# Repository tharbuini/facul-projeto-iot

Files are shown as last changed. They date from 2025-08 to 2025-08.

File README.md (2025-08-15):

# facul-projeto-iot

Desenvolvimento de Hardware para IoT.

```mermaid
graph TD
    A["Alimentação 5V / USB-C"] --> B{"Módulo Regulador 3.3V"}
    B --> C["ESP32-C3 Microcontrolador"]

    C -- I2C --> D["Sensor BME280 (Temp, Umid, Pressão)"]
    C -- GPIO (ADC) --> E["Sensor MQ-135 (Gases Poluentes)"]
    C -- Serial (UART) --> F["Sensor PMS5003 (Material Particulado)"]
    C -- I2C --> G["Display OLED 0.96"]
    C -- GPIO --> H["Botão de Ação"]

    C -- Wi-Fi --> I["Internet"]
    I -- MQTT/HTTPS --> J["Plataforma IoT (AWS IoT Core, Google Cloud IoT Core)"]
    J -- Armazenamento/Análise --> K["Banco de Dados / Serviço de Análise"]
    K -- Visualização/Alertas --> L["Dashboard Web / Aplicativo Móvel"]

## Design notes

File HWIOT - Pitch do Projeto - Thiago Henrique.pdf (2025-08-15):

# Projeto AtmoSense

# Thiago Henrique

# Problema e a Solução

### - Problema: qualidade do ar interno pode ser pior que a externa, afetando saúde (alergias, problemas respiratórios) e bem-estar. Não há

monitoramento fácil ou acessível.

### - Solução: dispositivo IoT compacto para monitoramento contínuo da

qualidade do ar em casa (AtmoSense).

# Visão Geral do Projeto

### - Objetivo: Oferecer visibilidade sobre a qualidade do ar, permitindo ações

preventivas e melhorando o ambiente doméstico.

### - Features:

- Dados em tempo real via nuvem.
- Interface local simples (display OLED).
- Alertas configuráveis.

# Arquitetura do Hardware

- SoC Central: ESP32-C3FH4X
- Sensores Principais:
- PMS7003: Material particulado (PM2.5, PM10).
- BME680: Temperatura, Umidade, Pressão e Gases VOC (voláteis orgânicos).
- Interface Local: Display OLED 0.96" (I2C), Botão de Reset e Botão de Pareamento.
- Alimentação: Fonte AC/DC chaveada em bloco, para operação contínua.
- Antena: integrada na PCB (residencial).
- Modelo Mecânico: Caixa compacta e discreta para mesa/parede, com ventilação.

# Diagrama de Blocos

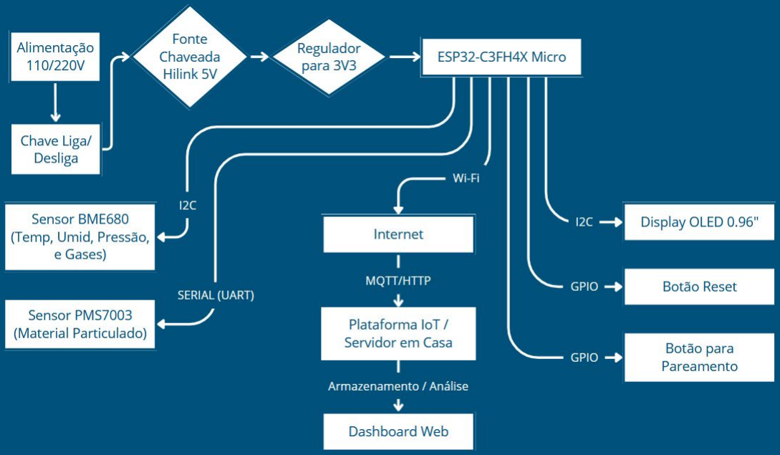
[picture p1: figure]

# Estimativa de Consumo

- Consumo total por ciclo:
- Em operação (30 s):
■ | ESP32FH4X ~= 200mA
■ | BME680 = 20mA (era 12 típico)
■ | Display OLED 0.96" = 20mA
■ | PMS7003 = 100mA
■ | Arredondando para cima, ~350mA em operação por 30s
- Em deep-sleep (10 min):
■ 5uA
- Total: 2.91mAh/ciclo
- Ciclos por dia:
- 86400[s]/630[s] ~= 137,14 ciclos/dia
- Consumo total por dia:
- 2.91 * 137,14 ~= 399,1 mAh/dia

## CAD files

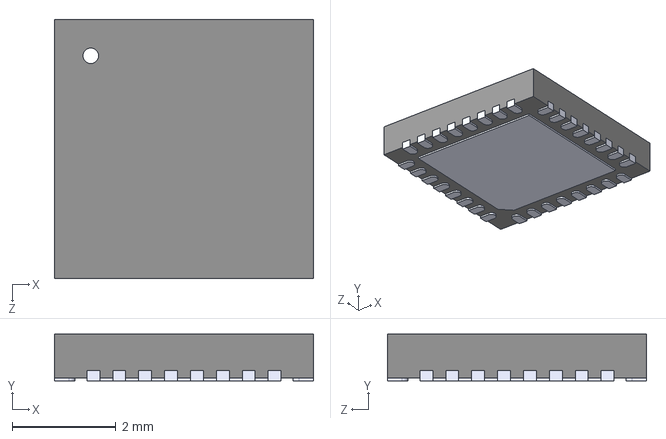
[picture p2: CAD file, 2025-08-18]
atmo_sense/STEPS/ESP32-C3FH4.step
5.00 x 0.9 x 5.00 mm

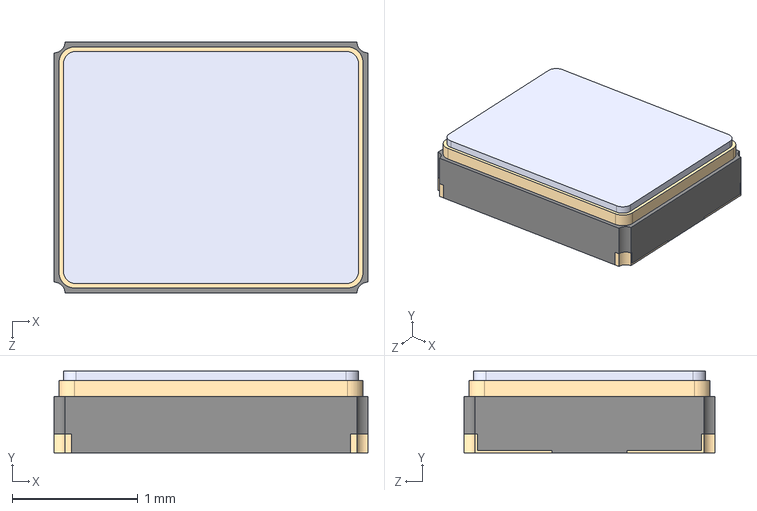
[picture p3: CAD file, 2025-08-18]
atmo_sense/STEPS/ECS-400-10-36B-CKY-TR.step
2.50 x 0.65 x 2.00 mm

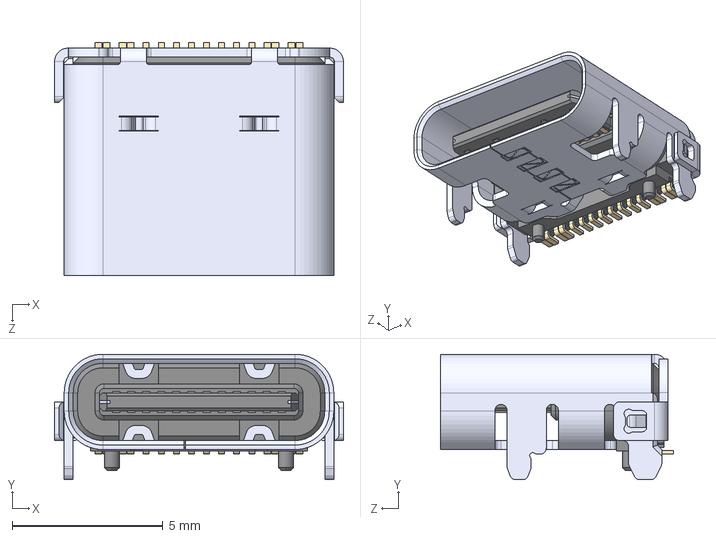
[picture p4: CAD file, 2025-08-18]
atmo_sense/STEPS/USB4105-GF-A.step
9.58 x 4.16 x 7.71 mm

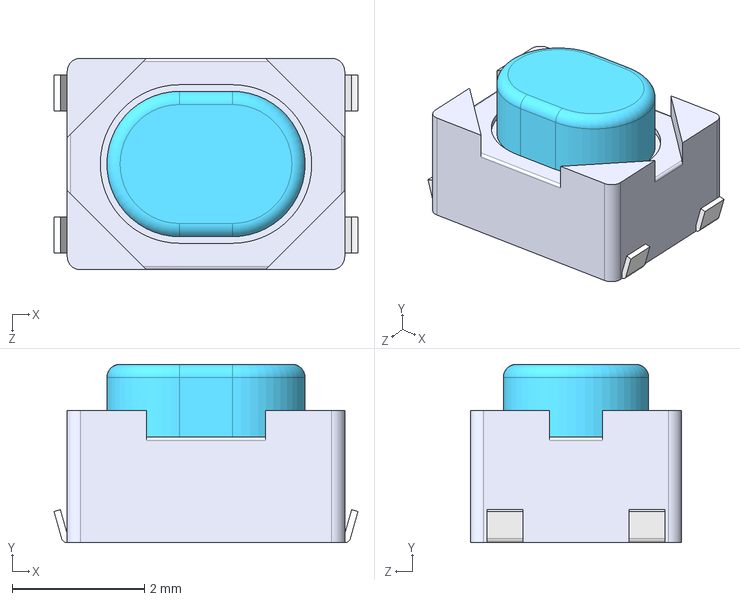
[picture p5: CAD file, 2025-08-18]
atmo_sense/STEPS/PTS810SJK250SMTRLFS.step
4.60 x 2.70 x 3.20 mm

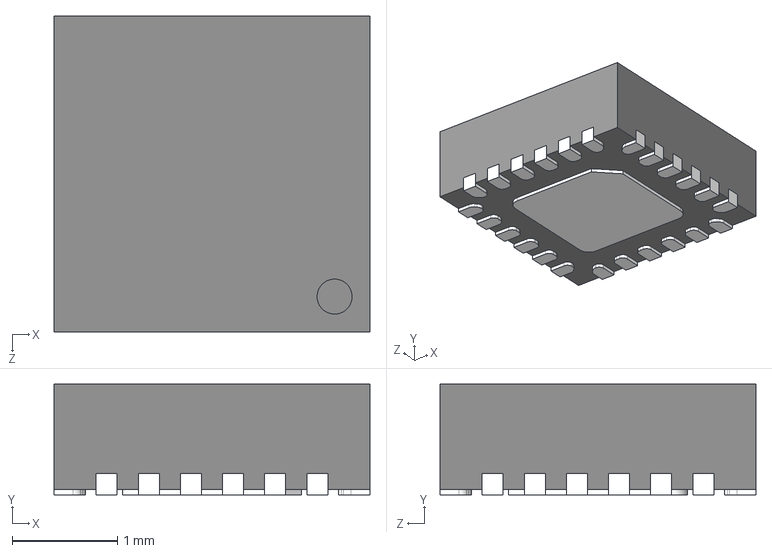
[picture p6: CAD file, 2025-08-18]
atmo_sense/STEPS/MPU-9250.step
3.00 x 1.05 x 3.00 mm

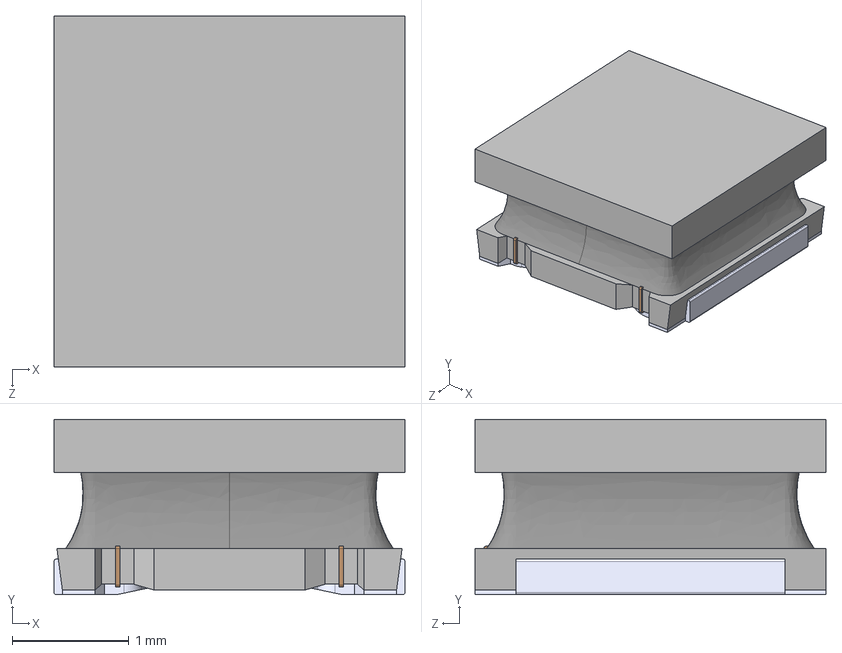
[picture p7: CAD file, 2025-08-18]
atmo_sense/STEPS/LQH3NPN2R2MMEL.step
3.00 x 1.50 x 3.00 mm

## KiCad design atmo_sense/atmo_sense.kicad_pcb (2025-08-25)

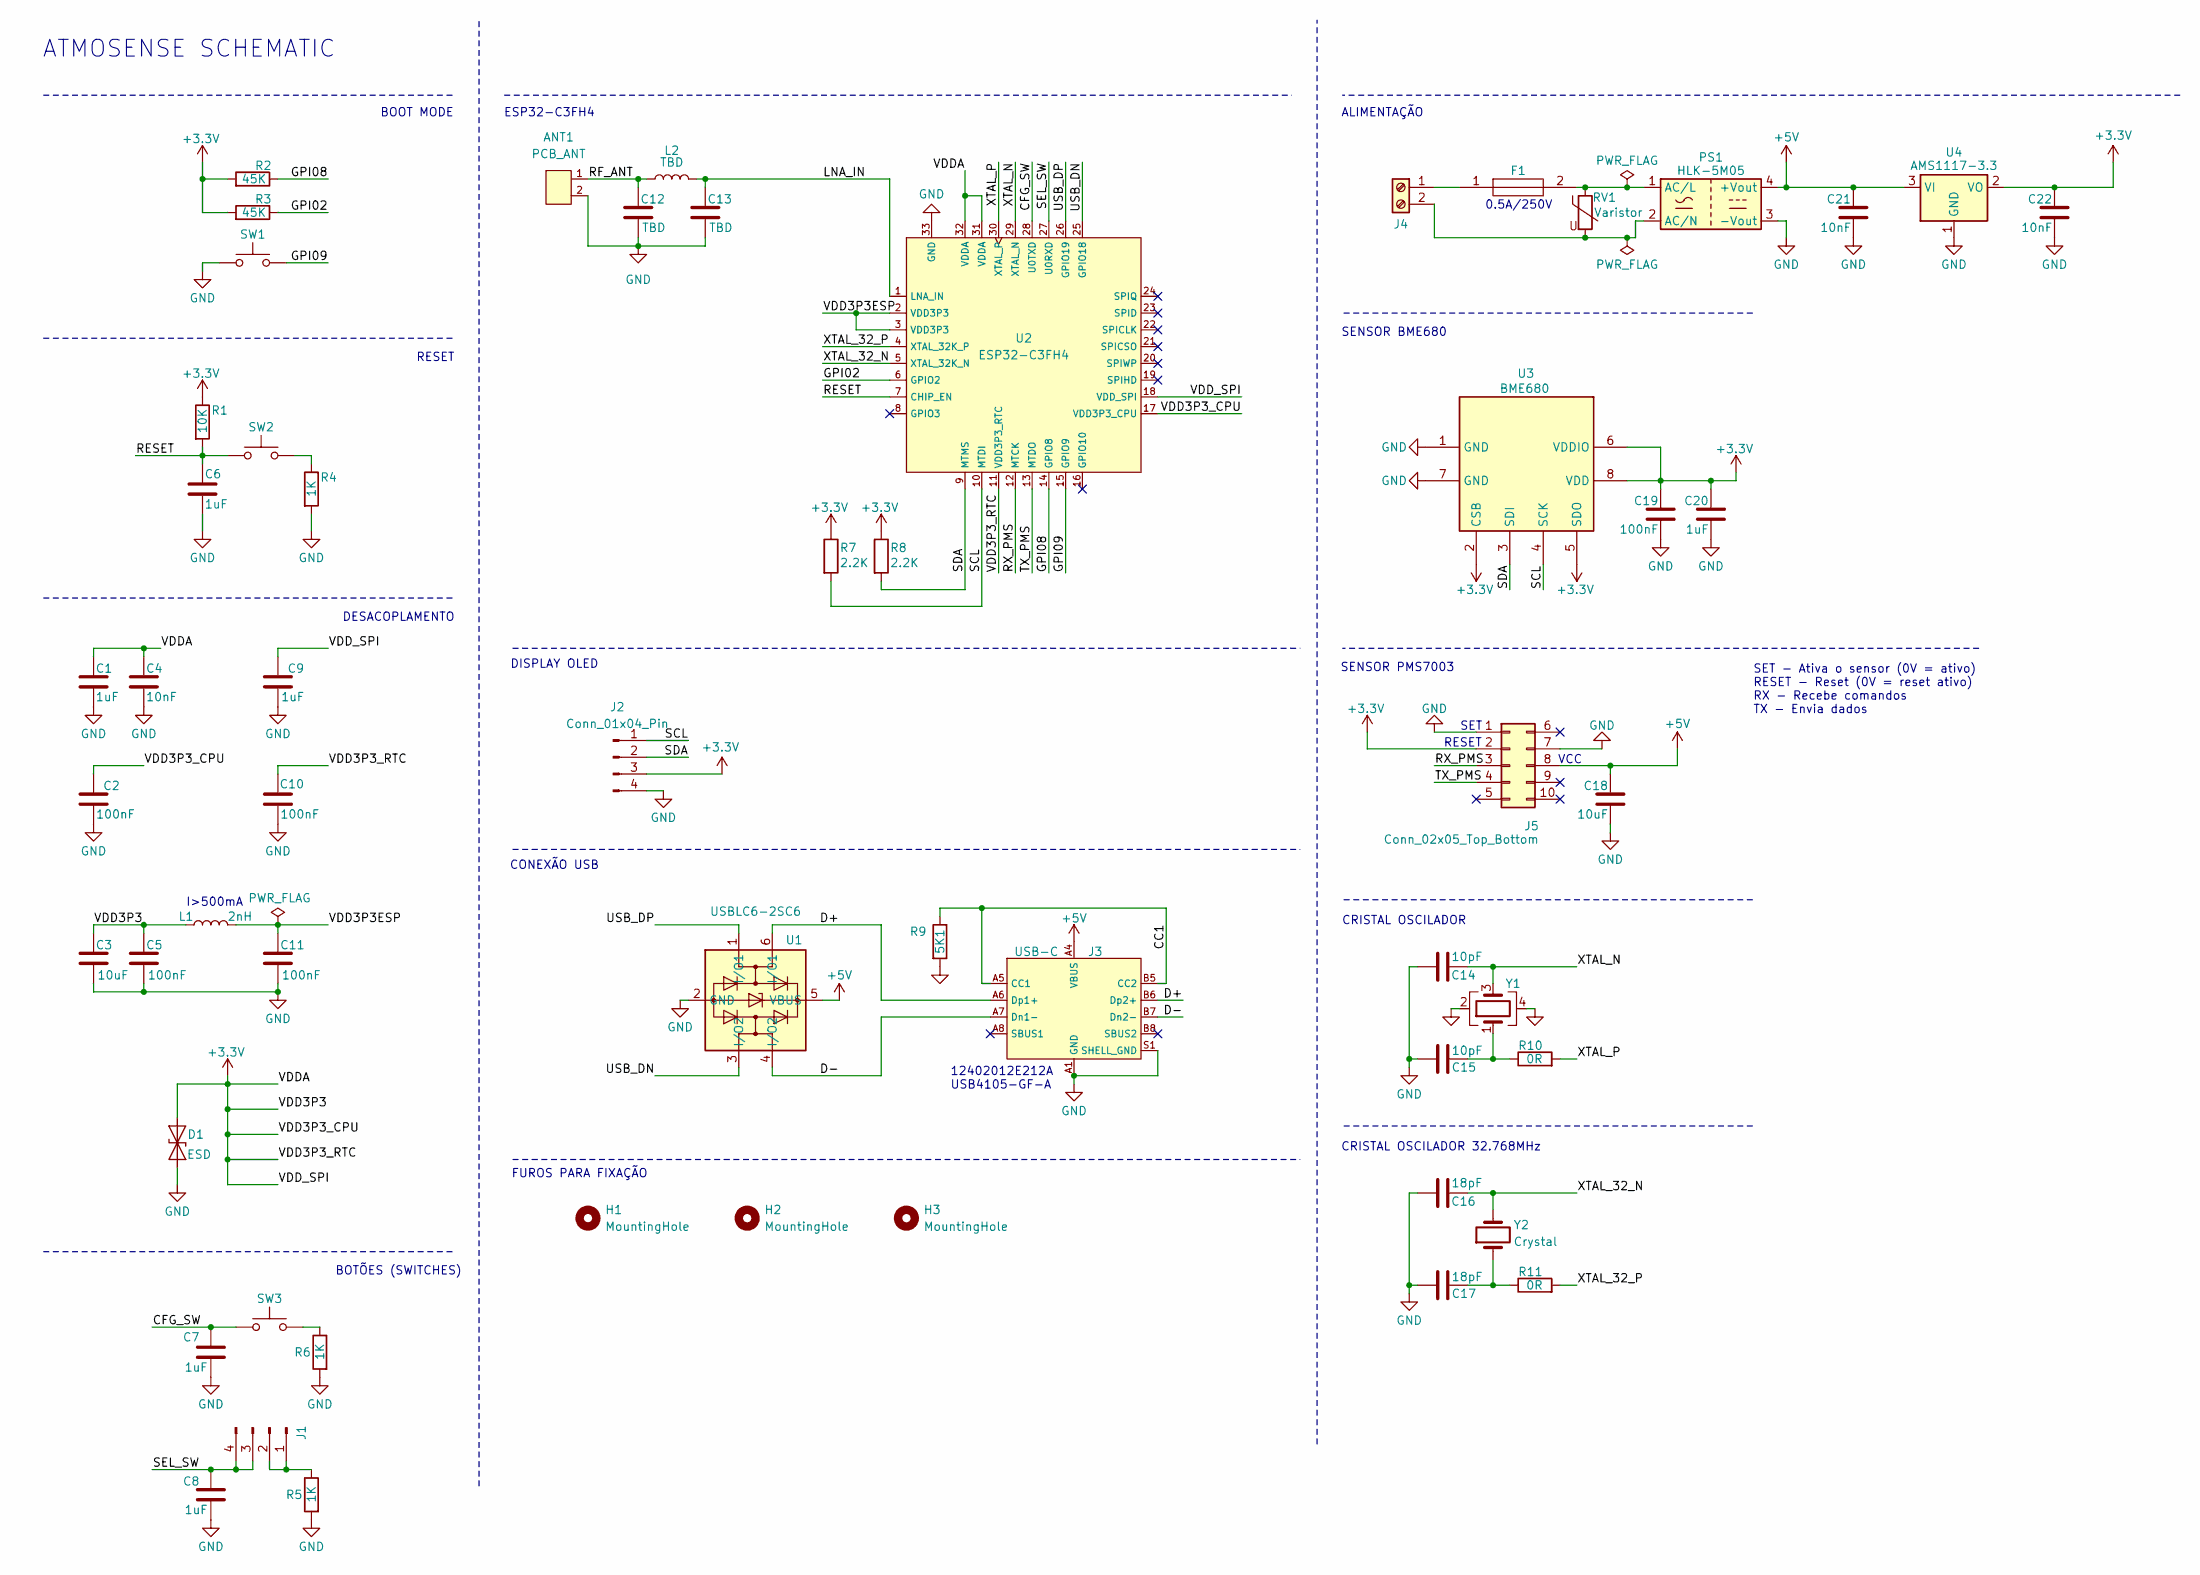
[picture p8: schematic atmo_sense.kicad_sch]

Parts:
ANT1: PCB_ANT; Texas_SWRA117D_2.4GHz_Left
C1, C6, C7, C8, C9, C20: 1uF; C_0402_1005Metric
C2, C5, C10, C11, C19: 100nF; C_0402_1005Metric
C3: 10uF; C_0603_1608Metric
C4, C21, C22: 10nF; C_0402_1005Metric
C12, C13: TBD; C_0402_1005Metric
C14, C15: 10pF; C_0402_1005Metric
C16, C17: 18pF; C_0402_1005Metric
C18: 10uF; C_0402_1005Metric
D1: ESD; D_SOD-923
F1: SF-2410SP050W-2; Fuse_2512_6332Metric; Mouser Part Number 652-SF-2410SP050W-2
H1, H2, H3: MountingHole; MountingHole_2mm
J1: Conn_01x04_Pin; PinSocket_2x02_P2.00mm_Vertical
J2: Conn_01x04_Pin; PinSocket_1x04_P2.00mm_Vertical
J3: USB-C; USB_C_Receptacle_XKB_U262-16XN-4BVC11
J4: TB007-508-02BE; TerminalBlock_Phoenix_MKDS-1,5-2-5.08_1x02_P5.08mm_Horizont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
J5: Conn_02x05_Top_Bottom; PinSocket_2x05_P2.00mm_Vertical
L1: 2nH; L_0402_1005Metric
L2: TBD; L_0402_1005Metric
PS1: HLK-5M05; Converter_ACDC_Hi-Link_HLK-5Mxx
R1: 10K; R_0402_1005Metric
R2, R3: 45K; R_0402_1005Metric
R4: 1K; R_0402_1005Metric
R5, R6: 1K; R_0603_1608Metric
R7, R8: 2.2K; R_0402_1005Metric
R9: 5K1; R_0402_1005Metric
R10, R11: 0R; R_0402_1005Metric
RV1: Varistor; RV_Disc_D7mm_W4.3mm_P5mm
SW1, SW2, SW3: SW_Push; SW_SPST_PTS810
U1: USBLC6-2SC6; SOT-23-6
U2: ESP32-C3FH4; QFN-32-1EP_5x5mm_P0.5mm_EP3.7x3.7mm
U3: BME680; Bosch_LGA-8_3x3mm_P0.8mm_ClockwisePinNumbering
U4: AMS1117-3.3; SOT-223-3_TabPin2
Y1: ECS-400-10-36B2-CKM-TR; Crystal_SMD_2520-4Pin_2.5x2.0mm
Y2: Crystal; Crystal_SMD_2520-4Pin_2.5x2.0mm

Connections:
+3.3V: C1.1, C2.1, C3.1, C4.1, C5.1, C9.1, C10.1, C19.1, C20.1, C22.1, D1.2 (A2), J2.3, J5.2, L1.1, R1.1, R2.2, R3.2, R7.1, R8.1, U2.11 (VDD3P3_RTC), U2.17 (VDD3P3_CPU), U2.18 (VDD_SPI), U2.31 (VDDA), U2.32 (VDDA), U3.2 (CSB), U3.5 (SDO), U3.6 (VDDIO), U3.8 (VDD), U4.2 (VO)
+5V: C18.1, C21.1, J3.A4 (VBUS), J3.A9 (VBUS), J3.B4 (VBUS), J3.B9 (VBUS), J5.8, PS1.4 (+Vout), U1.5 (VBUS), U4.3 (VI)
/CC1: J3.A5 (CC1), J3.B5 (CC2), R9.1
/CFG_SW: C7.1, SW3.2, U2.28 (U0TXD)
/D+: J3.A6 (Dp1+), J3.B6 (Dp2+), U1.6 (I/O1)
/D-: J3.A7 (Dn1-), J3.B7 (Dn2-), U1.4 (I/O2)
/GPI02: R3.1, U2.6 (GPIO2)
/GPI08: R2.1, U2.14 (GPIO8)
/GPI09: SW1.1, U2.15 (GPIO9)
/LNA_IN: C13.1, L2.2, U2.1 (LNA_IN)
/RESET: C6.1, R1.2, SW2.1, U2.7 (CHIP_EN)
/RF_ANT: ANT1.1, C12.1, L2.1
/RX_PMS: J5.3, U2.12 (MTCK)
/SCL: J2.1, R7.2, U2.10 (MTDI), U3.4 (SCK)
/SDA: J2.2, R8.2, U2.9 (MTMS), U3.3 (SDI)
/SEL_SW: C8.1, J1.3, J1.4, U2.27 (U0RXD)
/TX_PMS: J5.4, U2.13 (MTDO)
/USB_DN: U1.3 (I/O2), U2.25 (GPIO18)
/USB_DP: U1.1 (I/O1), U2.26 (GPIO19)
/VDD3P3ESP: C11.1, L1.2, U2.2 (VDD3P3), U2.3 (VDD3P3)
/XTAL_32_N: C16.2, U2.5 (XTAL_32K_N), Y2.2
/XTAL_32_P: R11.2, U2.4 (XTAL_32K_P)
/XTAL_N: C14.2, U2.29 (XTAL_N), Y1.3
/XTAL_P: R10.2, U2.30 (XTAL_P)
GND: ANT1.2, C1.2, C2.2, C3.2, C4.2, C5.2, C6.2, C7.2, C8.2, C9.2, C10.2, C11.2, C12.2, C13.2, C14.1, C15.2, C16.1, C17.2, C18.2, C19.2, C20.2, C21.2, C22.2, D1.1 (A1), J2.4, J3.A1 (GND), J3.A12 (GND), J3.B1 (GND), J3.B12 (GND), J3.S1 (SHELL_GND), J5.1, J5.7, PS1.3 (-Vout), R4.2, R5.2, R6.2, R9.2, SW1.2, U1.2 (GND), U2.33 (GND), U3.1 (GND), U3.7 (GND), U4.1 (GND), Y1.2, Y1.4
unnamed: C15.1, R10.1, Y1.1
unnamed: C17.1, R11.1, Y2.1
unnamed: J1.1, J1.2, R5.1
unnamed: F1.1, J4.1
unnamed: J4.2, PS1.2 (AC/N), RV1.2
unnamed: F1.2, PS1.1 (AC/L), RV1.1
unnamed: R4.1, SW2.2
unnamed: R6.1, SW3.1

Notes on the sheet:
SET - Ativa o sensor (0V = ativo) RESET - Reset (0V = reset ativo) RX - Recebe comandos TX - Envia dados
SENSOR BME680
CRISTAL OSCILADOR
CRISTAL OSCILADOR 32.768MHz
SENSOR PMS7003
12402012E212A USB4105-GF-A
ALIMENTAÇÃO
CONEXÃO USB
DISPLAY OLED
ATMOSENSE SCHEMATIC
0.5A/250V
RESET
SET
BOTÕES (SWITCHES)
FUROS PARA FIXAÇÃO
BOOT MODE
I>500mA
DESACOPLAMENTO
ESP32-C3FH4
VCC

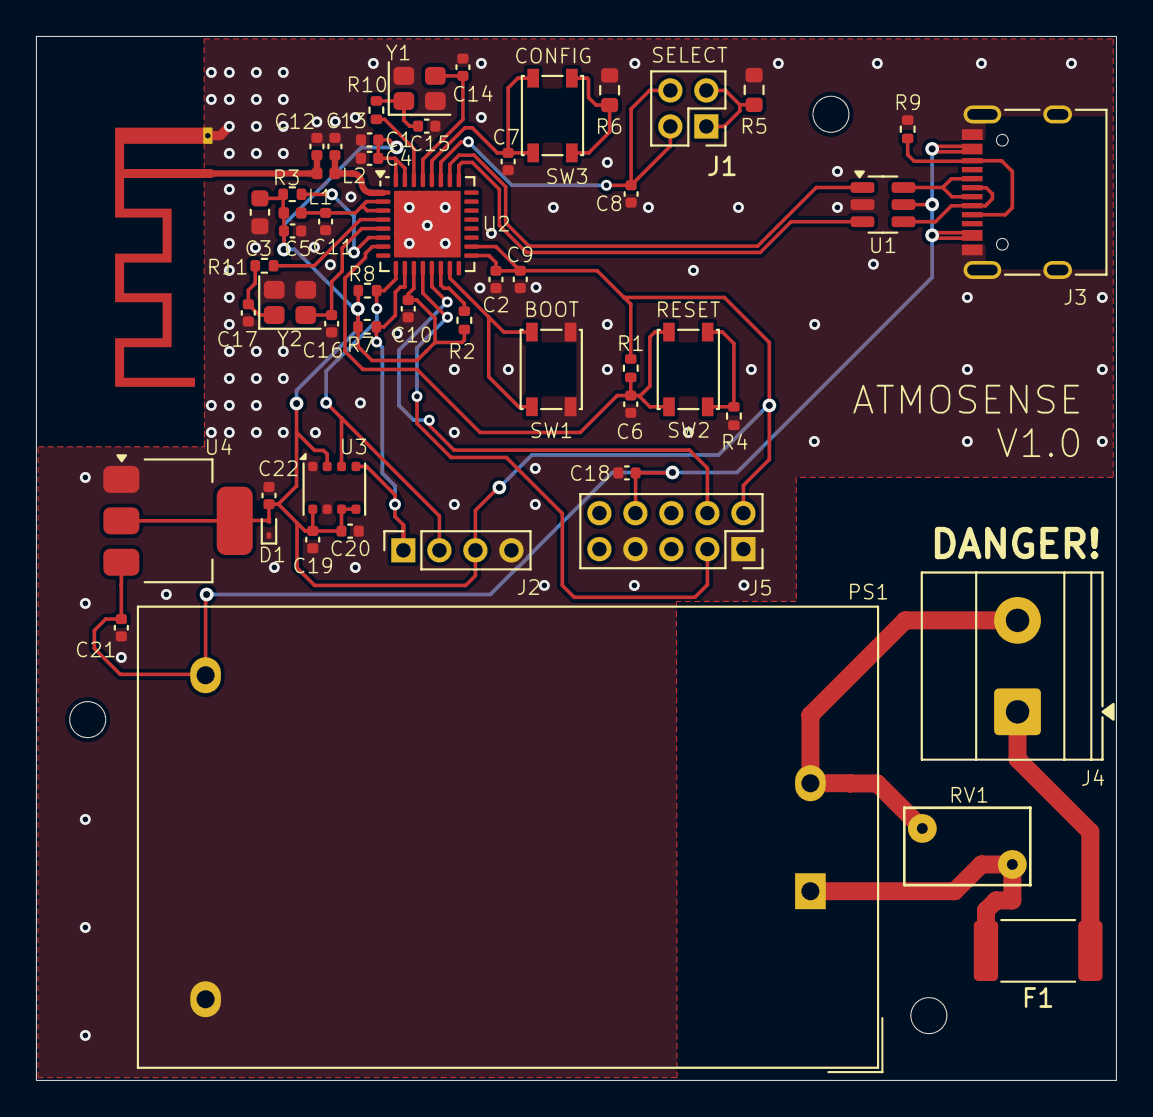
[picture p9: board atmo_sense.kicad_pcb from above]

Board: 4 copper layers, 60.0 x 58.0 mm, 57 parts (0 on the bottom side), 33 nets.

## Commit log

2025-08-15 Backup inicial
    [atmo_sense.kicad_pcb, atmo_sense.kicad_sch]
2025-08-19 PCB design
    [atmo_sense.kicad_pcb, atmo_sense.kicad_sch]
